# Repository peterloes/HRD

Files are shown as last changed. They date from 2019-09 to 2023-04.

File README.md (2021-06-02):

# A Handheld Readout Device(HRD) for Battery Management Systems
Monitoring Battery Quality and reduce waste.

A standalone HRD to enable long-term diagnostic observations and 
documentation of battery quality.

Supported:

- TEXAS INSTRUMENTS bq40z50
- ATMEL ATmega32HVB

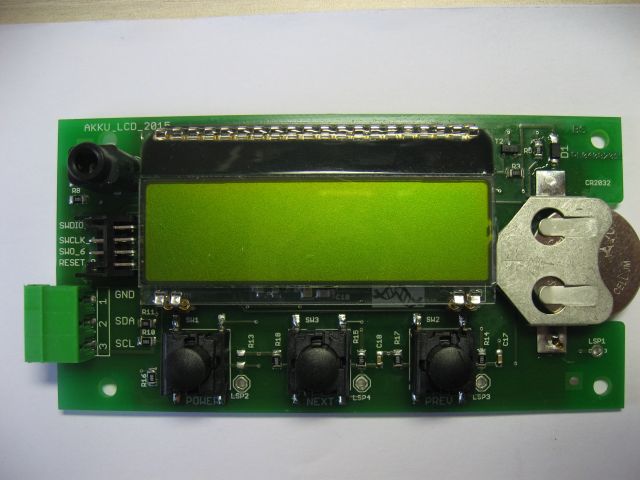
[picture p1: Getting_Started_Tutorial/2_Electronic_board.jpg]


Rechargeable batteries are more and more dominating our modern life.
We find them in our smartphones and notebooks, in e-bikes and e-cars but also in many toys and
basically everywhere where wired power supply is absent.
The charge state of these batteries is usually reported by highlighting a certain portion of a bar, representing full charge.
But is this indication always correct and how can I check whether the full capacity of my battery is still available?

In many rechargeable batteries, technical parameters are controlled by a Battery Management System(BMS).
This device monitors physical parameters like Voltage, Current, Temperature and State of Charge but also
calculates useful values like "Total Number of Charge Cycles", "Total Operation Time since First Use "or"
Energy Delivered since Last Charge".

In product manufacturing, this information is important for checking the battery quality before final assembly
on the product. For battery-driven medical devices, reliable knowledge about the battery status can be crucial.
For the end-user of a battery driven device, access to these data would be beneficial to allow for an informed decision
whether the device could be repaired or needs to be replaced.
 
The efficient use of batteries is especially important, as batteries are difficult to recycle and thus constitute a
burden for the environment. Unfortunately, common BMSs do not display the stored data by default.

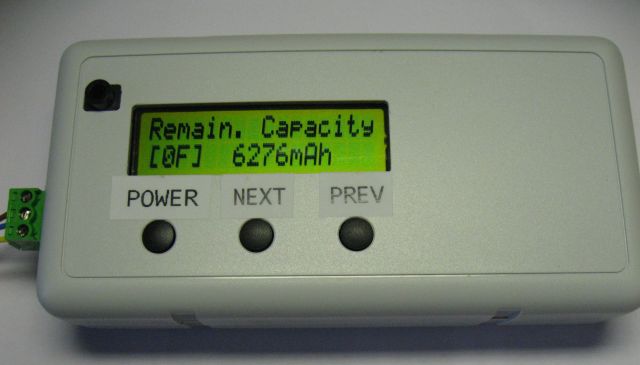
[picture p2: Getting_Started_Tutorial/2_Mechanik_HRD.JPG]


Battery controller probing requests. 0x0A=Atmel, 0x16=TI

Actual Current is signed.

Power management for the LC-Display.

Display will be scrolled (11 digits).

HRD can be connected to external devices like personal computers to transfer and store the extracted technical data.

https://github.com/peterloes/HRD/blob/master/Getting_Started_Tutorial/1_poster_overview.pdf

Manufacture:

https://github.com/peterloes/HRD/blob/master/Getting_Started_Tutorial/3_Supplier.txt

The standalone HRD features EFM32 ...the world´s most energy friendly microcontrollers

ARM Cortex-M3 EFM32G230F128

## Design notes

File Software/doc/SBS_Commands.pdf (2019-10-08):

# Projekt U-BMS2-4

# SBS-

# Commands

# SBS Commands

Device Address | | | | | | 0x0A
ManufacturerAccess | | | | | | 0x00

Read word

RemainingCapacityAlarm | 0x01

Read word
Rückgabe des remainingCapacityAlarm-Wertes in [mAh].

Wenn die Restkapazität(remainingCapacity) kleiner als der Wert vom RemainingCapacityAlarm ist, sendet die Batterie eine Alarmwarnung zum Host. Der RemainingCapacityAlarm-Flag im Battery-Status wird gesetzt.

RemainingTimeAlarm | 0x02

Read word
Rückgabe des remainingTimeAlarm -Wertes in [min].

Wenn die durchschnittliche Entladezeit des Akkus(AverageTimeToEmpty) kleiner als der Wert vom
RemainingTimeAlarm | ist, | sendet | die | Batterie | eine | Alarmwarnung | zum | Host. | Der
RemainingTimeAlarm-Flag im Battery-Status wird gesetzt.
Battery Mode | | | | | | 0x03

Read word

Bit | Beschreibung

### 12 BALANCING CELL3

### 11 BALANCING CELL2

### 10 BALANCING CELL1

### 6 BALANCING CELL4

### 5 Deep Under Voltage recovery(DUVRD) Bit vom FET Control and Status-Register

(FCSR)

### 4 Current Protection Status (CPS) Bit vom FET Control and Status-Register (FCSR)

### 3 Discharge FET (DFE) Bit vom FET Control and Status-Register (FCSR)

### 2 Charge FET (CFE) Bit vom FET Control and Status-Register (FCSR)

CoreTemperature | 0x08

Read word
Die aktuelle Chip-Temperatur in [°K]
Voltage | 0x09

Read word
Die gesamte Akkuspannung in [mV]
BatteryCurrent | 0x0A

Read word
Der aktuelle Strom in [mA], der aus bzw. in den Akkupack durchfließt.
BatteryAverageCurrent | 0x0B

Read word
Der durchschnittliche Strom des Akkupacks in [mA]
RelativeStateOfCharge | 0x0D

Read word
Der relative Ladezustand des Akkupacks in [%]
AbsoluteStateOfCharge | 0x0E

Read word
Der absolute Ladezustand des Akkupacks in [%]
RemainingCapacity | 0x0F

Read word
Die Restkapazität des Akkupacks in [mAh]
FullChargeCapacity | 0x10

Read word
Rückgabe der vollen Ladekapazität in [mAh]
RunTimeToEmpty | 0x11

Read word
Die Ladezeit in [min]
AverageTimeToEmpty | 0x12

Read word
Die durchschnittliche Entladezeit [min]
AverageTimeToFull | 0x13

Read word
Die durchschnittliche Ladezeit in [min]

ChargingCurrent | 0x14

Read word
Der Ladestrom in [mA]
ChargingVoltage | 0x15

Read word
Die maximale Ladespannung in [mV]
Battery Status (flags) | 0x16

Read word

Bit | Beschreibung

### 15 Over Charged Alarm

Überprüfung des chargingProhibited-Flags

### 14 Terminate Charge Alarm

Überprüfung des voltageTooHigh-Flags

### 12 Over Temp Alarm

Überprüfung des cellTemperatureTooHigh -Flags

### 11 Terminante Discharge Alarm

Dieses Bit wird gesetzt, wenn die Restkapazität unter dem definierten Wert von SBS_TERMINATE_DISCHARGE_LIMIT (Standard 5mAh) liegt. Wenn ein Ladegerät erkannt wird, wird dieses Bit gelöscht.

### 10 Battery Protection Triggered

Dieses Bit wird gesetzt, wenn die Batterieschutz-Hardware die FETs ausschaltet.

### 9 Remaining Capacity Alarm

Dieses Bit wird gesetzt, wenn die Restkapazität weniger als der definierte Wert des Restkapazität-Alarms(RemainingCapacityAlarm) ist.

### 8 Remaining Time Alarm :

Wenn die durchschnittlische Entladezeit (AverageTimeToEmpty) kleiner als der definierte Wert des Entladezeit-Alarms (RemainingTimeAlarm) ist, wird dieses Bit gesetzt.

### 7 Initialized

Dieses Bit wird gesetzt, wenn die Initialisierung erfolgreich abgeschlossen ist.

### 6 Discharging

Dieses Bit wird gesetzt, wenn ein Entladestrom fließt.

### 5 Fully Charged

Dieses Bit wird gesetzt, wenn die Batterie vollständig geladen ist. Wenn ein Entladestrom aus der Batterie fließt, der höher als der Standby-Stromwert ist, wird dieses Bit gelöscht.

### 4 Fully Discharged

Dieses Bit wird gesetzt, wenn die Restkapazität der Batterie bzw. die Zellenspannung sehr niedrig ist. Wenn der relative Ladezustand über 20% steigt, wird dieses Bit gelöscht.

ChargerCycleCount | 0x17

Read word
Die Anzahl der Ladezyklen
DesignCapacity | 0x18

Read word
Die Nennkapazität in [mAh]
DesignVoltage | 0x19

Read word
Die Nennspannung in [mV]
SpecificationInfo | 0x1A

Read word
Die Spezifikation-Info (Version und Revision-Nummer)
ManufactureDate | 0x1B

Read word
Das Herstellungsdatum
SerialNumber | 0x1C

Read word
Die Seriennummer
ManufacturerName | 0x20

Read Block
Der Name des Herstellers
DeviceName | 0x21

Read Block
Der Name des Gerätes
DeviceChemistry | 0x22

Read Block
Die chemische Bezeichnung des Gerätes
ManufacturerData | 0x23

Read Block
Die Herstellerdaten
ShuntResistance | 0x2A

Read word
Der Wert des Shunt-Widerstands in [µOhm]

CellsInSeries | 0x3C

Read word
Anzahl der verwendeten Zellen in Serie
OverCurrentReactionTime | 0x3D

Read word
Überstrom Reaktionszeit Stufe 1
OverCurrentCharge | 0x3E

Read word
Überladestrom Stufe 1
OverCurrentDischarge | 0x3F

Read word
Überentladestrom Stufe 1
HighCurrentReactionTime | 0x40

Read word
Überstrom Reaktionszeit Stufe 2
HighCurrentCharge | 0x41

Read word
Überladestrom Reaktionszeit Stufe 2
HighCurrentDischarge | 0x42

Read word
Überentladestrom Stufe 2
VoltageCell4 | 0x44

Read word
Rückgabe der Spannung der Zelle 4 in [mV]
VoltageCell3 | 0x45

Read word
Rückgabe der Spannung der Zelle 3 in [mV]
VoltageCell2 | 0x46

Read word
Rückgabe der Spannung der Zelle 3 in [mV]

VoltageCell1 | 0x47

Read word
Rückgabe der Spannung der Zelle 1 in [mV]
CellMinVoltage | 0x54

Read word
Die minimale Zellenspannung in [mV]
CellMaxVoltage | 0x55

Read word
Der Wert der maximalen Zellenspannung in [mV]
CellPowerOffVoltage | 0x55

Read word
Der Wert der Zellenspannung in [mV], bei der das BMS in den PowerOffModus geht

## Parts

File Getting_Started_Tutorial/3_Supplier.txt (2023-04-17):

Supplier of all Electronic Boards

Top-Print Electronic GmbH
Oskar Schmid

Rosenheimer Landstr. 129a
85521 Ottobrunn
Germany
Tel.: +49-89-60668047
Fax: +49-89-60668049
mailto: info@top-print.eu
https://www.leiterplatten-muenchen.de/

https://www.reichelt.com

1 	× 	Housing TEKO Mod.10008
3 	× 	5GSH935+1SS09-12.0 (Button)
24 	× 	Pin Header, vertical to increase display height. manufacturer number: MK01/50 Z.
1 	× 	Phoenix Contact MC 1.5/ 3-G-3.81 manufacturer number: 1803280
1 	× 	PTR Socket housing-cable AK(Z)1550 manufacturer number: 51550030025F
1 	× 	FTDI Chip cable (3.5mm Audio Jack to USB) TTL-232R-3V3-AJ 

Docklight RS232 Terminal / RS232 Monitor
https://docklight.de/information/

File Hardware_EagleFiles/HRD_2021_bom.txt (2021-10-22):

Part  Value                         Device           Package          Description                                                    MF MPN OC_FARNELL OC_NEWARK
BH1   KEYSTONE_CELL_CLIP 3082 3082             3082                                                                                                       
C1    100n                          C-EUC0805K       C0805K           CAPACITOR, European symbol                                                                
C2    1u                            C-EUC0805K       C0805K           CAPACITOR, European symbol                                                                
C3    12p                           C-EUC0805K       C0805K           CAPACITOR, European symbol                                                                
C4    18p                           C-EUC0805K       C0805K           CAPACITOR, European symbol                                                                
C5    100n                          C-EUC0805K       C0805K           CAPACITOR, European symbol                                                                
C6    100n                          C-EUC0805K       C0805K           CAPACITOR, European symbol                                                                
C7    100n                          C-EUC0805K       C0805K           CAPACITOR, European symbol                                                                
C8    100n                          C-EUC0805K       C0805K           CAPACITOR, European symbol                                                                
C9    12p                           C-EUC0805K       C0805K           CAPACITOR, European symbol                                                                
C10   18p                           C-EUC0805K       C0805K           CAPACITOR, European symbol                                                                
C11   100n                          C-EUC0805K       C0805K           CAPACITOR, European symbol                                                                
C12   100n                          C-EUC0805K       C0805K           CAPACITOR, European symbol                                                                
C13   100n                          C-EUC0805K       C0805K           CAPACITOR, European symbol                                                                
C14   100n                          C-EUC0805K       C0805K           CAPACITOR, European symbol                                                                
C15   100n                          C-EUC0805K       C0805K           CAPACITOR, European symbol                                                                
C16   100n                          C-EUC0805K       C0805K           CAPACITOR, European symbol                                                                
C17   10n                           C-EUC0603K       C0603K           CAPACITOR, European symbol                                                                
C18   10n                           C-EUC0603K       C0603K           CAPACITOR, European symbol                                                                
C19   470n                          C-EUC0603K       C0603K           CAPACITOR, European symbol                                                                
C20   100n                          C-EUC0603K       C0603K           CAPACITOR, European symbol                                                                
C21   100nF                         C-EUC0603K       C0603K           CAPACITOR, European symbol                                                                
D1    RSX101M-30              DIODE-SOD123     SOD123           DIODE                                                                                     
IC1   EFM32G230F128                 EFM32G230F128    QFN64            EFM32G230F128 Gecko Microcontroller in 9mm x 9mm QFN64 package                            
J1    LUMBERG1502_01                LUMBERG1502_01   LUMBERG1502_01                                                                                             
LCD1  EA_DOGM162L-A           EA_DOGM162       EA_DOGM          ELECTRONIC ASSEMBYL GmbH                                                                  
LSP1  (n.b.)LSP13                   LSP13            LSP13            SOLDER PAD drill 1.3 mm, distributor Buerklin, 12H562                                     
LSP2  (n.b.)SE13                    SE13             SE13             SOLDER PAD E1542,  drill 1,3mm, distributor Buerklin, 07F815                              
LSP3  (n.b.)SE13                    SE13             SE13             SOLDER PAD E1542,  drill 1,3mm, distributor Buerklin, 07F815                              
LSP4  (n.b.)SE13                    SE13             SE13             SOLDER PAD E1542,  drill 1,3mm, distributor Buerklin, 07F815                              
PASS1 ROUND_1MM1.5                  ROUND_1MM1.5     ROUND2_1.5MM                                                                                               
PASS2 ROUND_1MM1.5                  ROUND_1MM1.5     ROUND2_1.5MM                                                                                               
Q1    NX5032GA/32MHz/8pF            CRYSTAL2P5.0X3.2 CRYSTAL2P5.0X3.2 Quarz Crystal                                                                             
Q2    CM7V, 32768Hz/12.5pF          CRYSTAL2P        CRYSTAL2P3.2X1.5 Quarz Crystal                                                                             
R1    100                           R-EU_R0805       R0805            RESISTOR, European symbol                                                                 
R2    100K                          R-EU_R0805       R0805            RESISTOR, European symbol                                                                 
R3    100K                          R-EU_R0805       R0805            RESISTOR, European symbol                                                                 
R4    100                           R-EU_R0805       R0805            RESISTOR, European symbol                                                                 
R5    100K                          R-EU_R0805       R0805            RESISTOR, European symbol                                                                 
R6    100                           R-EU_R0805       R0805            RESISTOR, European symbol                                                                 
R7    100K                          R-EU_R0805       R0805            RESISTOR, European symbol                                                                 
R8    10K                           R-EU_R0805       R0805            RESISTOR, European symbol                                                                 
R9    10K                           R-EU_R0805       R0805            RESISTOR, European symbol                                                                 
R10   1K                            R-EU_R0805       R0805            RESISTOR, European symbol                                                                 
R11   1K                            R-EU_R0805       R0805            RESISTOR, European symbol                                                                 
R12   1                             R-EU_R0805       R0805            RESISTOR, European symbol                                                                 
R13   (n.b.)100K                    R-EU_R0805       R0805            RESISTOR, European symbol                                                                 
R14   100K                          R-EU_R0805       R0805            RESISTOR, European symbol                                                                 
R15   100K                          R-EU_R0805       R0805            RESISTOR, European symbol                                                                 
R16   100                           R-EU_R0805       R0805            RESISTOR, European symbol                                                                 
R17   100                           R-EU_R0805       R0805            RESISTOR, European symbol                                                                 
R18   100                           R-EU_R0805       R0805            RESISTOR, European symbol                                                                 
R19   100                           R-EU_R0805       R0805            RESISTOR, European symbol                                                                 
R20   100K                          R-EU_R0805       R0805            RESISTOR, European symbol                                                                 
R21   100K                          R-EU_R0805       R0805            RESISTOR, European symbol                                                                 
R22   100                           R-EU_R0805       R0805            RESISTOR, European symbol                                                                 
R23   100K                          R-EU_R0805       R0805            RESISTOR, European symbol                                                                 
SW1   5GSH935                 5GSH935          MULTIMEC_5GSH935                                                                                           
SW2   5GSH935                 5GSH935          MULTIMEC_5GSH935                                                                                           
SW3   5GSH935                 5GSH935          MULTIMEC_5GSH935                                                                                           
T1    2N7002                        NMOSSOT23        SOT-23           MOS FET                                                               unknown    unknown  
T2    FDN358P                       ZETEX_PMOSSOT23  ZETEX_SOT-23     MOS FET                                                                                   
T3    2N7002                        NMOSSOT23        SOT-23           MOS FET                                                               unknown    unknown  
T4    2N7002                        ZETEX_NMOSSOT23  ZETEX_SOT-23     MOS FET                                                                                   
T5    FDN358P                       ZETEX_PMOSSOT23  ZETEX_SOT-23     MOS FET                                                                                   
X1    DF11_8DP_2DS            DP11_8DP_2DS     DP11_8DP-2DS                                                                                               
X2    MKDS1/3-3,81            MKDS1/3-3,81     3POL381          MKDS 1/3-3,81 - manufacturer number: Order No. 1803280                          
   
LCD1 under  24 × Pin Header, vertical to increase display height. manufacturer number: MK01/50 Z
X2 Phoenix Contact MC 1.5/ 3-G-3.81 manufacturer number: 1803280 

Housing TEKO Mod.10008 
5GSH935+1SS09-12.0 (Buttons)
PTR Socket housing-cable AK(Z)1550 manufacturer number: 51550030025F
FTDI Chip cable (3.5mm Audio Jack to USB) TTL-232R-3V3-AJ

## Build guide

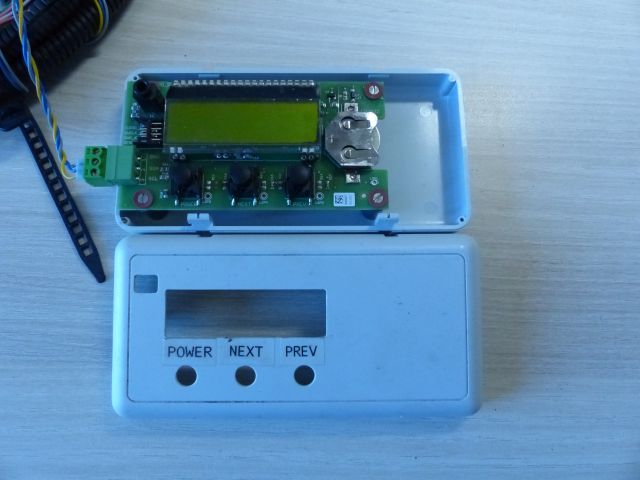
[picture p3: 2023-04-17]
Getting_Started_Tutorial/4_housing.jpg

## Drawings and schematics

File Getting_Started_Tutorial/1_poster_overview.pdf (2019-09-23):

## Handheld Readout Device (HRD)

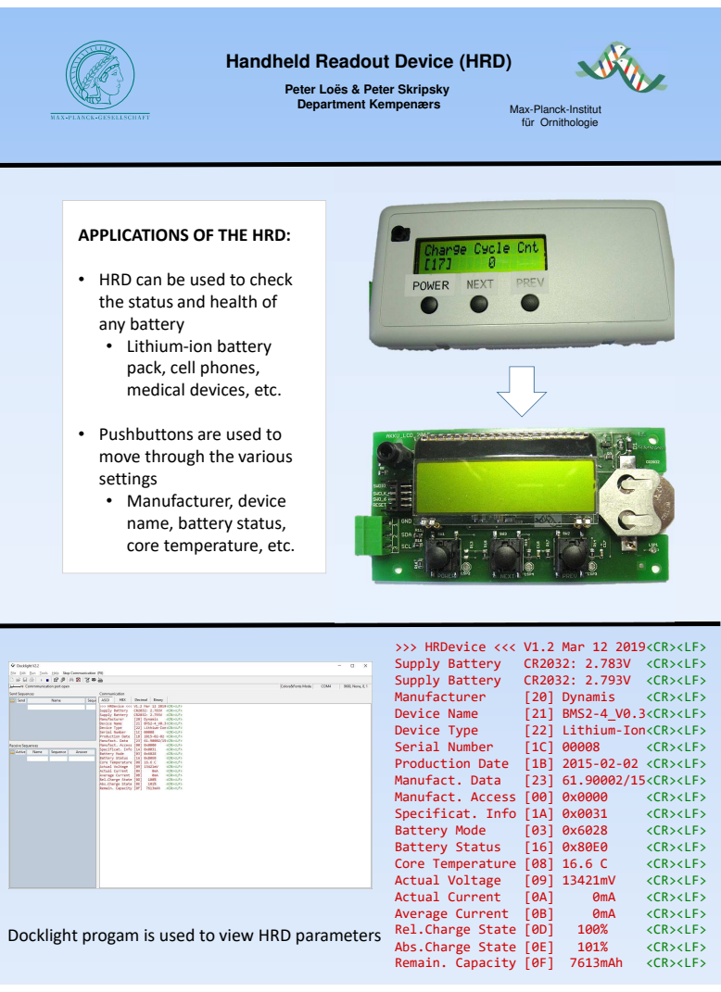
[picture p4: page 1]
Supply Battery; Manufacturer; [20] Dynamis; Device Name; [21] BMS2-4_V0.3<CR><LF>; Device Type; [22] Lithium-Ion<CR><LF>; Serial Number; Production Date; Manufact. Data; Manufact. Access [00] 0x0000; Specificat. Info [1A] 0x0031; Battery Mode; Battery Status; Core Temperature [08] 16.6 C; Actual Voltage; Actual Current; Average Current; Rel.Charge State [0D]; Abs.Charge State [0E]; Remain. Capacity [0F]; 7613mAh

Peter Loës & Peter Skripsky
Department Kempenærs

Max-Planck-Institut
für Ornithologie

APPLICATIONS OF THE HRD:

• HRD can be used to check
the status and health of
any battery
• Lithium-ion battery
pack, cell phones,
medical devices, etc.

• Pushbuttons are used to
move through the various
settings
• Manufacturer, device
name, battery status,
core temperature, etc.

>>> HRDevice <<< V1.2 Mar 12 2019<CR><LF>

Docklight progam is used to view HRD parameters

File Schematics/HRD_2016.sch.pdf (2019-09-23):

# EFM32 Power SMBUS / ATmega 32 HVB

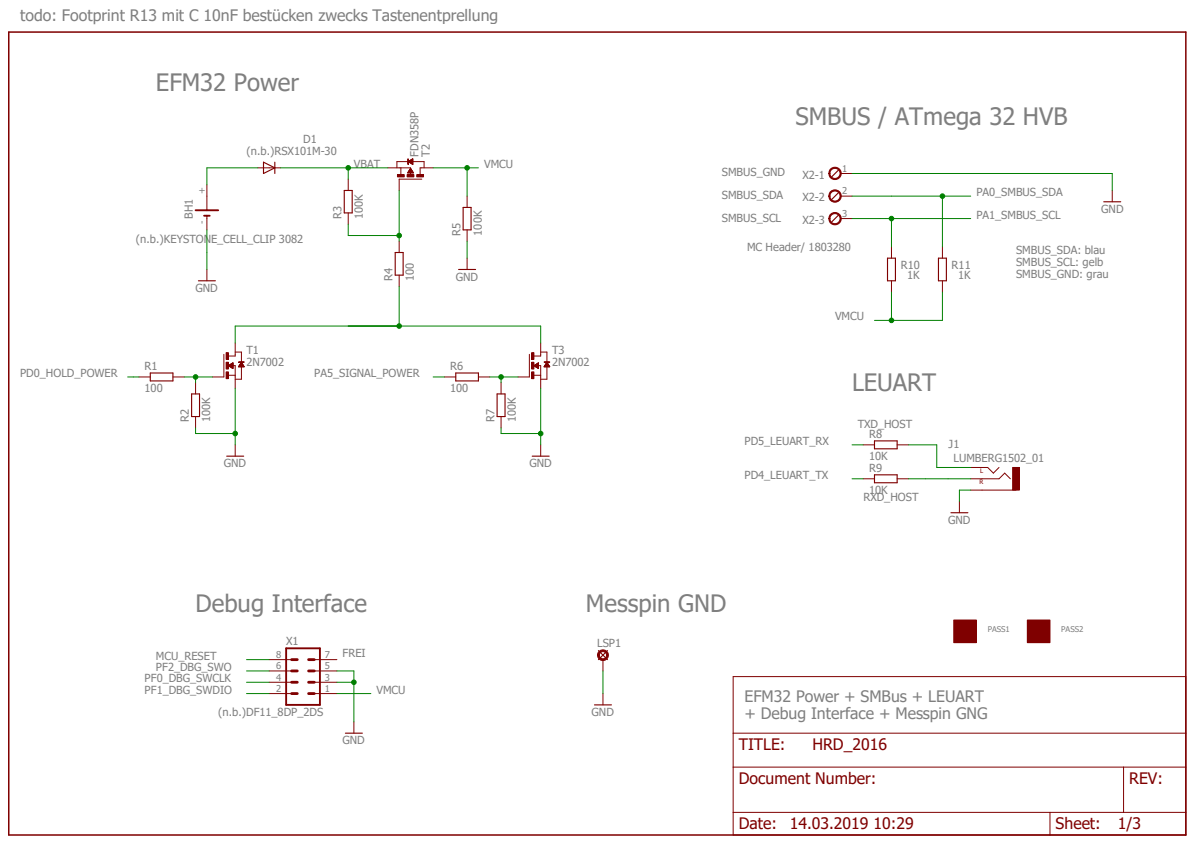
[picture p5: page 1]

todo: Footprint R13 mit C 10nF bestücken zwecks Tastenentprellung

EFM32 Power + SMBus + LEUART
+ Debug Interface + Messpin GNG

Document Number: | REV:

Date: 14.03.2019 10:29 | Sheet: 1/3

# EFM32 I/O + POWER

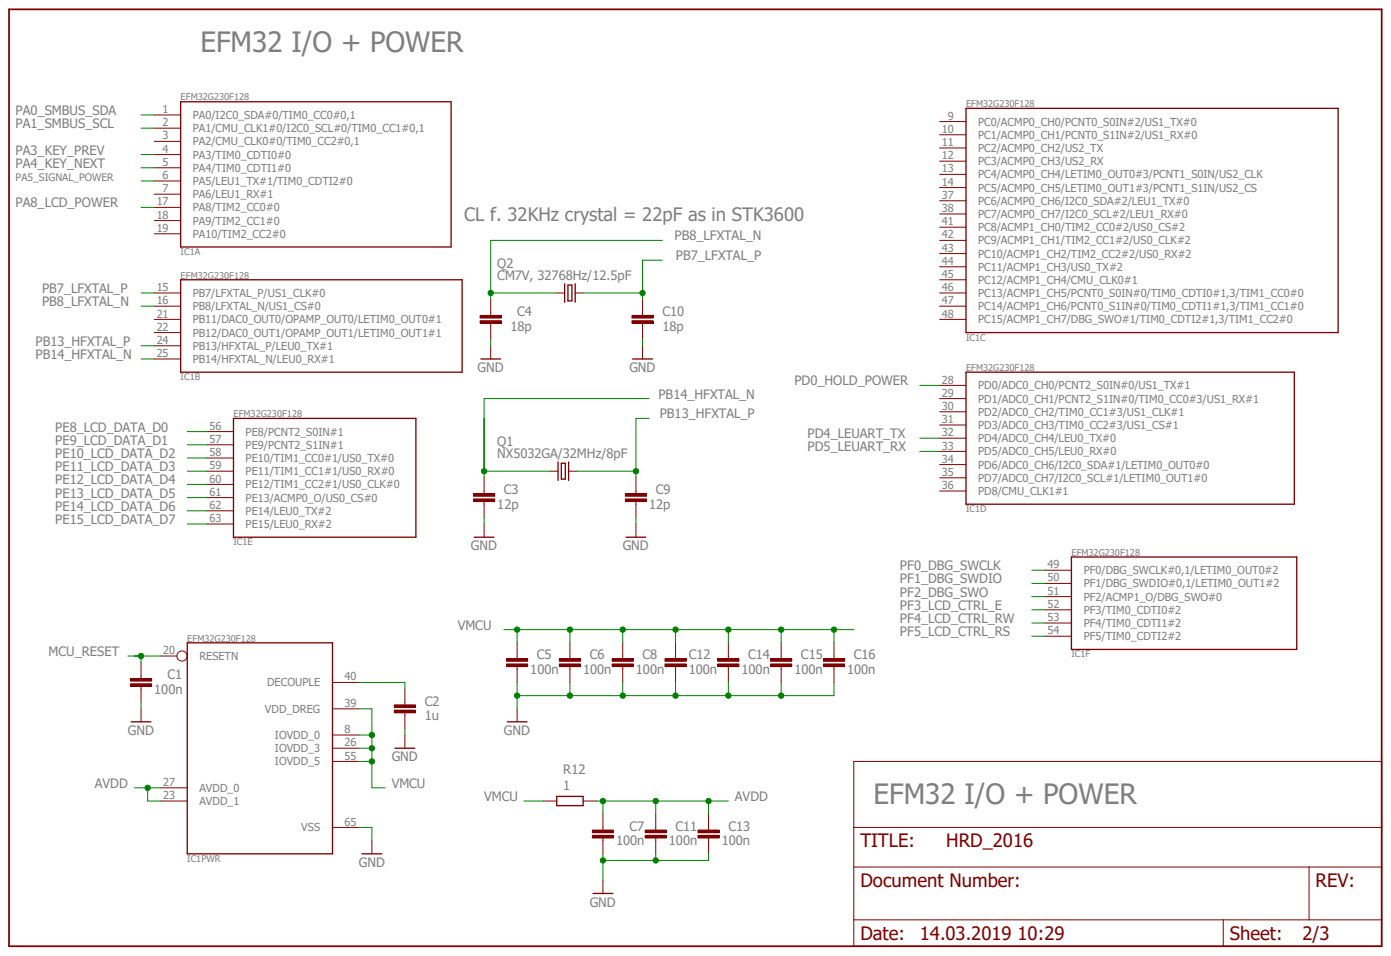
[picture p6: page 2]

CL f. 32KHz crystal = 22pF as in STK3600

Document Number: | REV:

Date: 14.03.2019 10:29 | Sheet: 2/3

# Display

Pushbutton | gemessen: AN 342uA

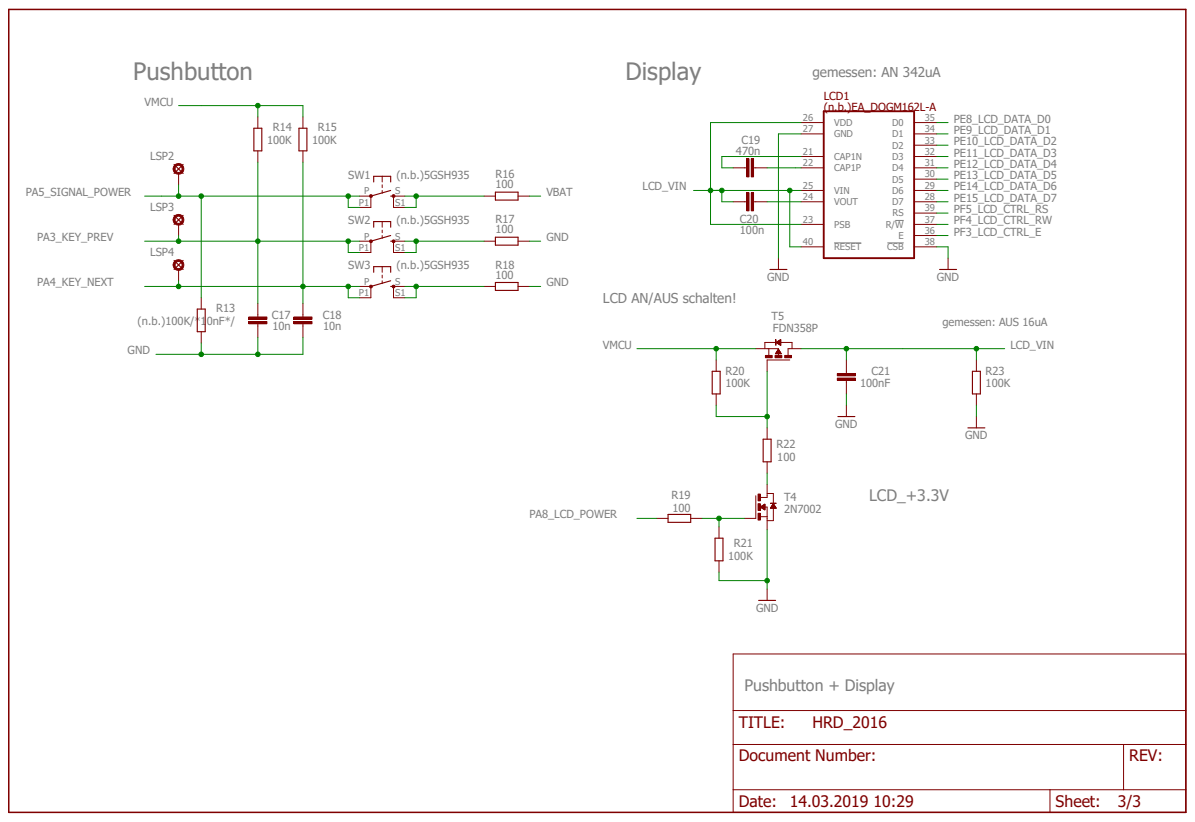
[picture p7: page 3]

LCD AN/AUS schalten!

Document Number: | REV:

Date: 14.03.2019 10:29 | Sheet: 3/3

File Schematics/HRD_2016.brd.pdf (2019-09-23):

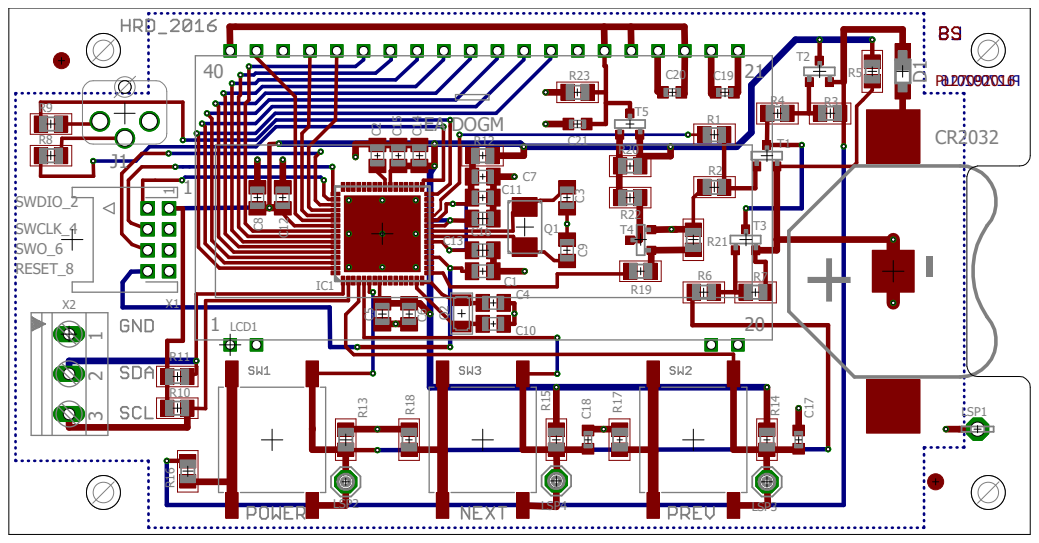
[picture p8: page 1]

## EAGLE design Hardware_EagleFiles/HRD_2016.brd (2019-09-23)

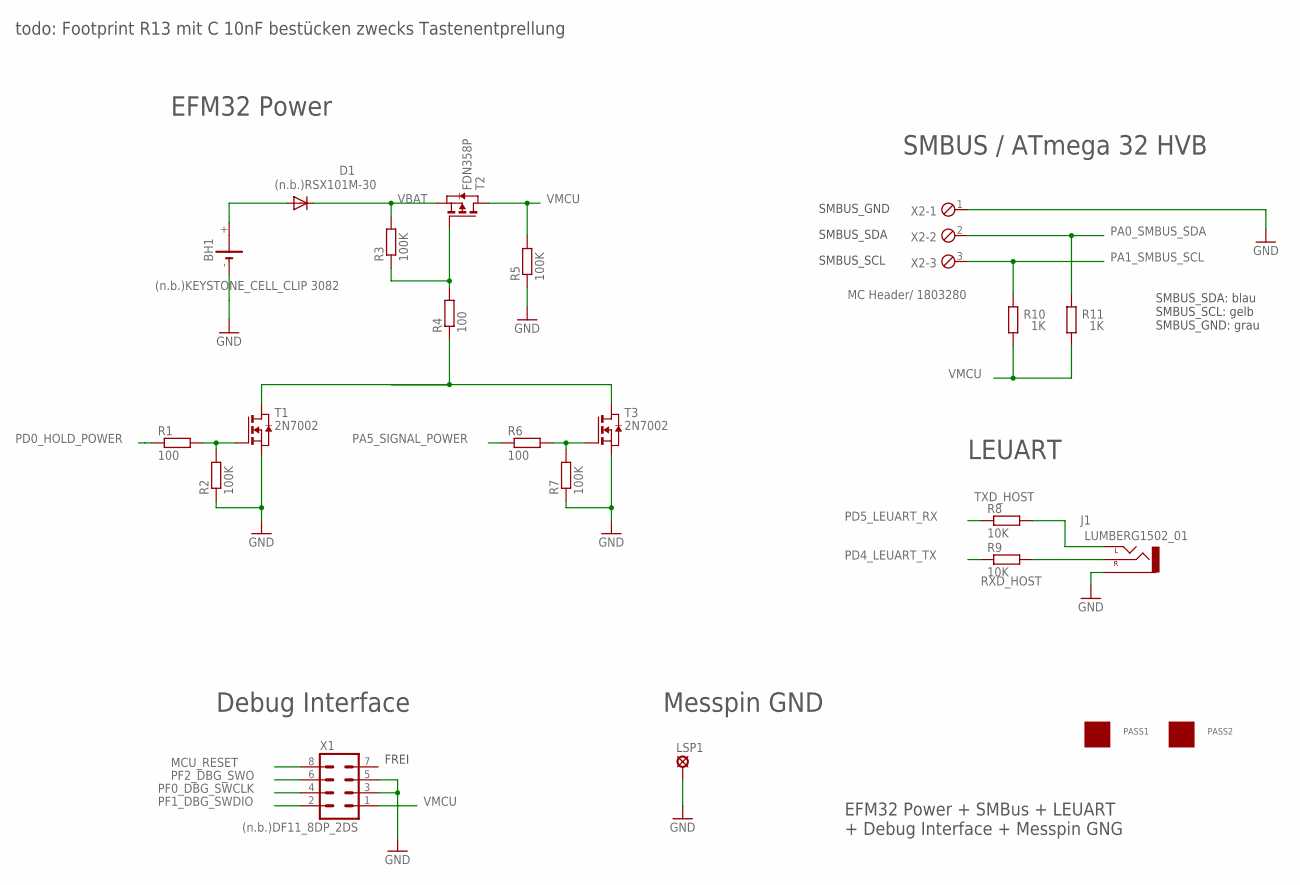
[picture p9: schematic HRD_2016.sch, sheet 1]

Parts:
BH1: (n.b.)KEYSTONE_CELL_CLIP 3082; 3082
D1: (n.b.)RSX101M-30; SOD123
J1: LUMBERG1502_01
LSP1: (n.b.)LSP13; LSP13
PASS1, PASS2: ROUND_1MM1.5; ROUND2_1.5MM
R1, R4, R6: 100; R0805
R2, R3, R5, R7: 100K; R0805
R8, R9: 10K; R0805
R10, R11: 1K; R0805
T1, T3: 2N7002; SOT-23
T2: FDN358P; ZETEX_SOT-23
X1: (n.b.)DF11_8DP_2DS; DP11_8DP-2DS
X2: MC Header/ 1803280; 3POL381

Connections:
GND: BH1.-, J1.P$1 (1-SLEEVE), LSP1.MP, R2.1, R5.1, R7.1, T1.2 (S), T3.2 (S), X1.3, X1.5, X2.1; also elsewhere on the board
MCU_RESET: X1.8; also elsewhere on the board
unnamed: BH1.+, D1.A
unnamed: R1.2, R2.2, T1.3 (G)
unnamed: R4.1, T1.1 (D), T3.1 (D)
unnamed: R6.2, R7.2, T3.3 (G)
unnamed: R3.1, R4.2, T2.3 (G)
PA0_SMBUS_SDA: R11.2, X2.2; also elsewhere on the board
PA1_SMBUS_SCL: R10.2, X2.3; also elsewhere on the board
PA5_SIGNAL_POWER: R6.1; also elsewhere on the board
PD0_HOLD_POWER: R1.1; also elsewhere on the board
PD4_LEUART_TX: R9.1; also elsewhere on the board
PD5_LEUART_RX: R8.1; also elsewhere on the board
PF0_DBG_SWCLK: X1.4; also elsewhere on the board
PF1_DBG_SWDIO: X1.2; also elsewhere on the board
PF2_DBG_SWO: X1.6; also elsewhere on the board
RXD_HOST: J1.P$3 (3-RIGHT), R9.2
TXD_HOST: J1.P$2 (2-LEFT), R8.2
VBAT: D1.C, R3.2, T2.2 (S); also elsewhere on the board
VMCU: R5.2, R10.1, R11.1, T2.1 (D), X1.1; also elsewhere on the board

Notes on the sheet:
EFM32 Power + SMBus + LEUART + Debug Interface + Messpin GNG
SMBUS_SCL
SMBUS_SDA
SMBUS_GND
EFM32 Power
Debug Interface
SMBUS / ATmega 32 HVB
FREI
SMBUS_SDA: blau SMBUS_SCL: gelb SMBUS_GND: grau
Messpin GND
LEUART
todo: Footprint R13 mit C 10nF bestücken zwecks Tastenentprellung

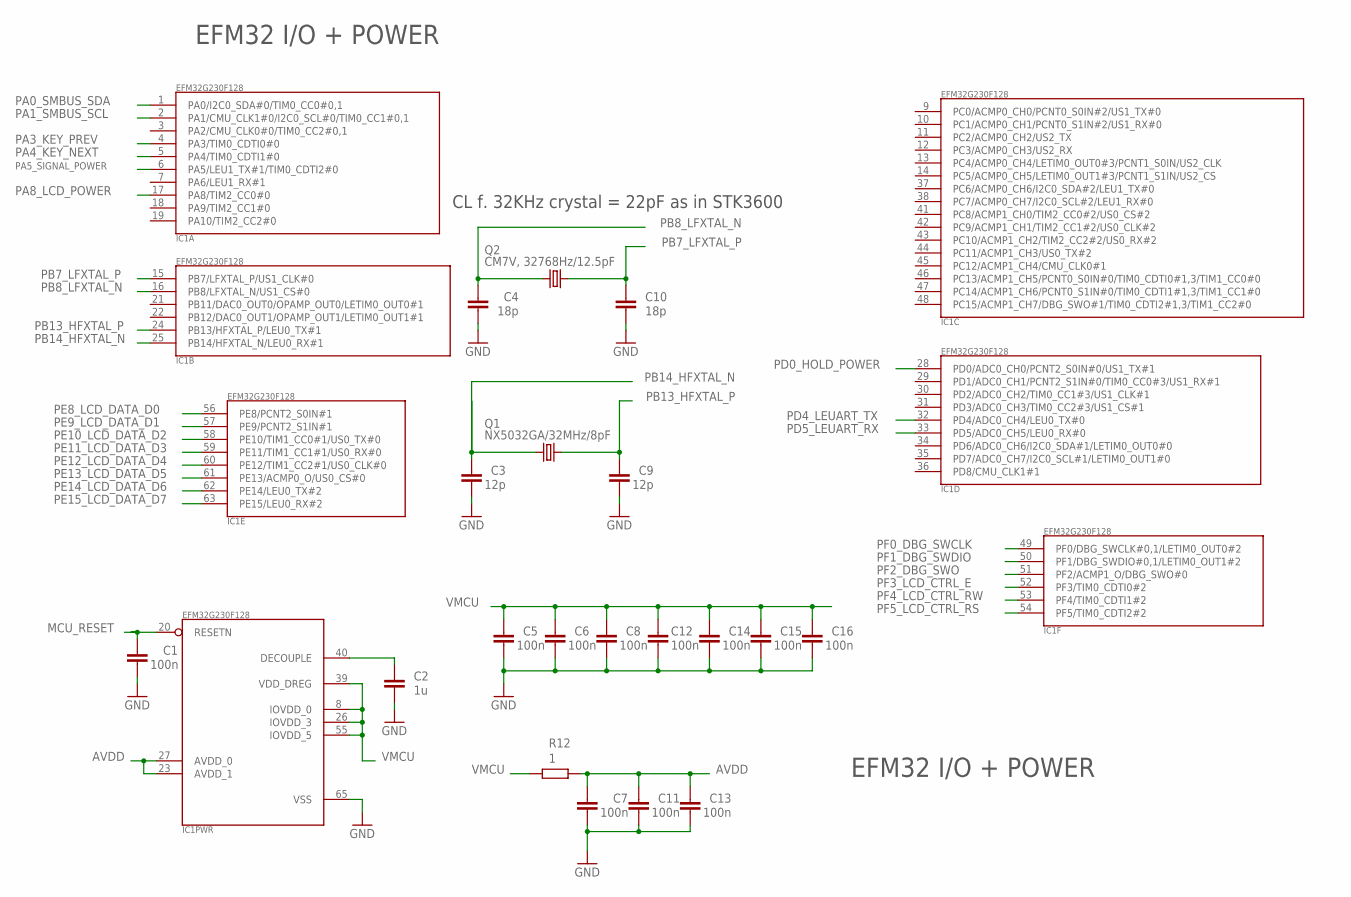
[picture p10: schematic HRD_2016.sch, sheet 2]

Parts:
C1, C5, C6, C7, C8, C11, C12, C13, C14, C15, C16: 100n; C0805K
C2: 1u; C0805K
C3, C9: 12p; C0805K
C4, C10: 18p; C0805K
IC1: EFM32G230F128; QFN64
Q1: NX5032GA/32MHz/8pF; CRYSTAL2P5.0X3.2
Q2: CM7V, 32768Hz/12.5pF; CRYSTAL2P3.2X1.5
R12: 1; R0805

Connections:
AVDD: C7.2, C11.2, C13.2, IC1.23 (AVDD_1), IC1.27 (AVDD_0), R12.2
GND: C1.1, C2.1, C3.1, C4.1, C5.1, C6.1, C7.1, C8.1, C9.1, C10.1, C11.1, C12.1, C13.1, C14.1, C15.1, C16.1, IC1.65 (VSS); also elsewhere on the board
MCU_RESET: C1.2, IC1.20 (RESETN); also elsewhere on the board
unnamed: C2.2, IC1.40 (DECOUPLE)
PA0_SMBUS_SDA: IC1.1 (PA0/I2C0_SDA#0/TIM0_CC0#0,1); also elsewhere on the board
PA1_SMBUS_SCL: IC1.2 (PA1/CMU_CLK1#0/I2C0_SCL#0/TIM0_CC1#0,1); also elsewhere on the board
PA3_KEY_PREV: IC1.4 (PA3/TIM0_CDTI0#0); also elsewhere on the board
PA4_KEY_NEXT: IC1.5 (PA4/TIM0_CDTI1#0); also elsewhere on the board
PA5_SIGNAL_POWER: IC1.6 (PA5/LEU1_TX#1/TIM0_CDTI2#0); also elsewhere on the board
PA8_LCD_POWER: IC1.17 (PA8/TIM2_CC0#0); also elsewhere on the board
PB7_LFXTAL_P: C10.2, IC1.15 (PB7/LFXTAL_P/US1_CLK#0), Q2.2
PB8_LFXTAL_N: C4.2, IC1.16 (PB8/LFXTAL_N/US1_CS#0), Q2.1
PB13_HFXTAL_P: C9.2, IC1.24 (PB13/HFXTAL_P/LEU0_TX#1), Q1.2
PB14_HFXTAL_N: C3.2, IC1.25 (PB14/HFXTAL_N/LEU0_RX#1), Q1.1
PD0_HOLD_POWER: IC1.28 (PD0/ADC0_CH0/PCNT2_S0IN#0/US1_TX#1); also elsewhere on the board
PD4_LEUART_TX: IC1.32 (PD4/ADC0_CH4/LEU0_TX#0); also elsewhere on the board
PD5_LEUART_RX: IC1.33 (PD5/ADC0_CH5/LEU0_RX#0); also elsewhere on the board
PE8_LCD_DATA_D0: IC1.56 (PE8/PCNT2_S0IN#1); also elsewhere on the board
PE9_LCD_DATA_D1: IC1.57 (PE9/PCNT2_S1IN#1); also elsewhere on the board
PE10_LCD_DATA_D2: IC1.58 (PE10/TIM1_CC0#1/US0_TX#0); also elsewhere on the board
PE11_LCD_DATA_D3: IC1.59 (PE11/TIM1_CC1#1/US0_RX#0); also elsewhere on the board
PE12_LCD_DATA_D4: IC1.60 (PE12/TIM1_CC2#1/US0_CLK#0); also elsewhere on the board
PE13_LCD_DATA_D5: IC1.61 (PE13/ACMP0_O/US0_CS#0); also elsewhere on the board
PE14_LCD_DATA_D6: IC1.62 (PE14/LEU0_TX#2); also elsewhere on the board
PE15_LCD_DATA_D7: IC1.63 (PE15/LEU0_RX#2); also elsewhere on the board
PF0_DBG_SWCLK: IC1.49 (PF0/DBG_SWCLK#0,1/LETIM0_OUT0#2); also elsewhere on the board
PF1_DBG_SWDIO: IC1.50 (PF1/DBG_SWDIO#0,1/LETIM0_OUT1#2); also elsewhere on the board
PF2_DBG_SWO: IC1.51 (PF2/ACMP1_O/DBG_SWO#0); also elsewhere on the board
PF3_LCD_CTRL_E: IC1.52 (PF3/TIM0_CDTI0#2); also elsewhere on the board
PF4_LCD_CTRL_RW: IC1.53 (PF4/TIM0_CDTI1#2); also elsewhere on the board
PF5_LCD_CTRL_RS: IC1.54 (PF5/TIM0_CDTI2#2); also elsewhere on the board
VMCU: C5.2, C6.2, C8.2, C12.2, C14.2, C15.2, C16.2, IC1.8 (IOVDD_0), IC1.26 (IOVDD_3), IC1.39 (VDD_DREG), IC1.55 (IOVDD_5), R12.1; also elsewhere on the board

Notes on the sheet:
EFM32 I/O + POWER
CL f. 32KHz crystal = 22pF as in STK3600

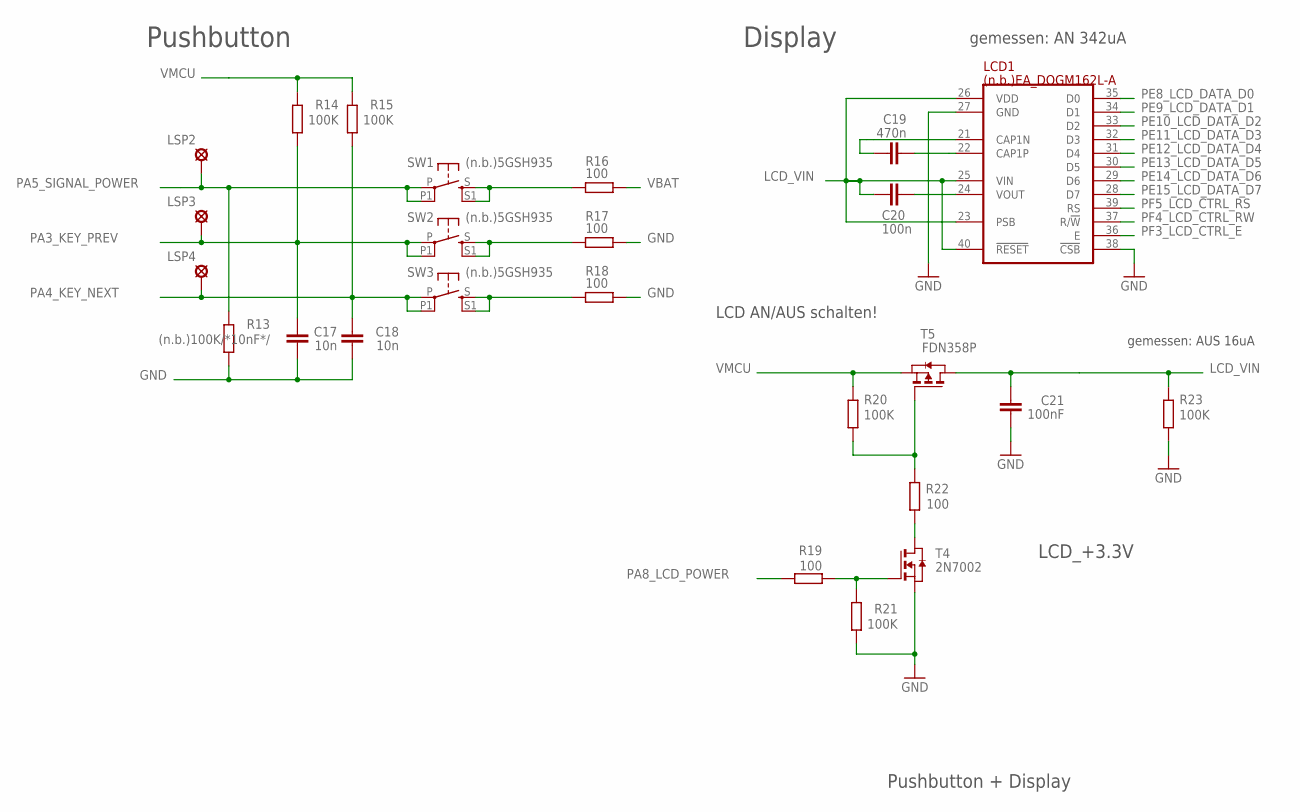
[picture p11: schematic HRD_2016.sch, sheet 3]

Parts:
C17, C18: 10n; C0603K
C19: 470n; C0603K
C20: 100n; C0603K
C21: 100nF; C0603K
LCD1: (n.b.)EA_DOGM162L-A; EA_DOGM
LSP2, LSP3, LSP4: (n.b.)SE13; SE13
R13: (n.b.)100K/*10nF*/; R0805
R14, R15, R20, R21, R23: 100K; R0805
R16, R17, R18, R19, R22: 100; R0805
SW1, SW2, SW3: (n.b.)5GSH935; MULTIMEC_5GSH935
T4: 2N7002; ZETEX_SOT-23
T5: FDN358P; ZETEX_SOT-23

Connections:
GND: C17.1, C18.1, C21.2, LCD1.27 (GND), LCD1.38 (!CSB!), R13.1, R17.2, R18.2, R21.1, R23.1, T4.2 (S); also elsewhere on the board
LCD_VIN: C20.2, C21.1, LCD1.23 (PSB), LCD1.25 (VIN), LCD1.26 (VDD), LCD1.40 (!RESET!), R23.2, T5.1 (D)
unnamed: R17.1, SW2.S, SW2.S1
unnamed: R16.1, SW1.S, SW1.S1
unnamed: R18.1, SW3.S, SW3.S1
unnamed: R20.1, R22.2, T5.3 (G)
unnamed: R22.1, T4.1 (D)
unnamed: R19.1, R21.2, T4.3 (G)
unnamed: C19.2, LCD1.22 (CAP1P)
unnamed: C19.1, LCD1.21 (CAP1N)
unnamed: C20.1, LCD1.24 (VOUT)
PA3_KEY_PREV: C17.2, LSP3.MP, R14.1, SW2.P, SW2.P1; also elsewhere on the board
PA4_KEY_NEXT: C18.2, LSP4.MP, R15.1, SW3.P, SW3.P1; also elsewhere on the board
PA5_SIGNAL_POWER: LSP2.MP, R13.2, SW1.P, SW1.P1; also elsewhere on the board
PA8_LCD_POWER: R19.2; also elsewhere on the board
PE8_LCD_DATA_D0: LCD1.35 (D0); also elsewhere on the board
PE9_LCD_DATA_D1: LCD1.34 (D1); also elsewhere on the board
PE10_LCD_DATA_D2: LCD1.33 (D2); also elsewhere on the board
PE11_LCD_DATA_D3: LCD1.32 (D3); also elsewhere on the board
PE12_LCD_DATA_D4: LCD1.31 (D4); also elsewhere on the board
PE13_LCD_DATA_D5: LCD1.30 (D5); also elsewhere on the board
PE14_LCD_DATA_D6: LCD1.29 (D6); also elsewhere on the board
PE15_LCD_DATA_D7: LCD1.28 (D7); also elsewhere on the board
PF3_LCD_CTRL_E: LCD1.36 (E); also elsewhere on the board
PF4_LCD_CTRL_RW: LCD1.37 (R/!W!); also elsewhere on the board
PF5_LCD_CTRL_RS: LCD1.39 (RS); also elsewhere on the board
VBAT: R16.2; also elsewhere on the board
VMCU: R14.2, R15.2, R20.2, T5.2 (S); also elsewhere on the board

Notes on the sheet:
Pushbutton + Display
Display
gemessen: AUS 16uA
LCD_+3.3V
LCD AN/AUS schalten!
gemessen: AN 342uA
Pushbutton

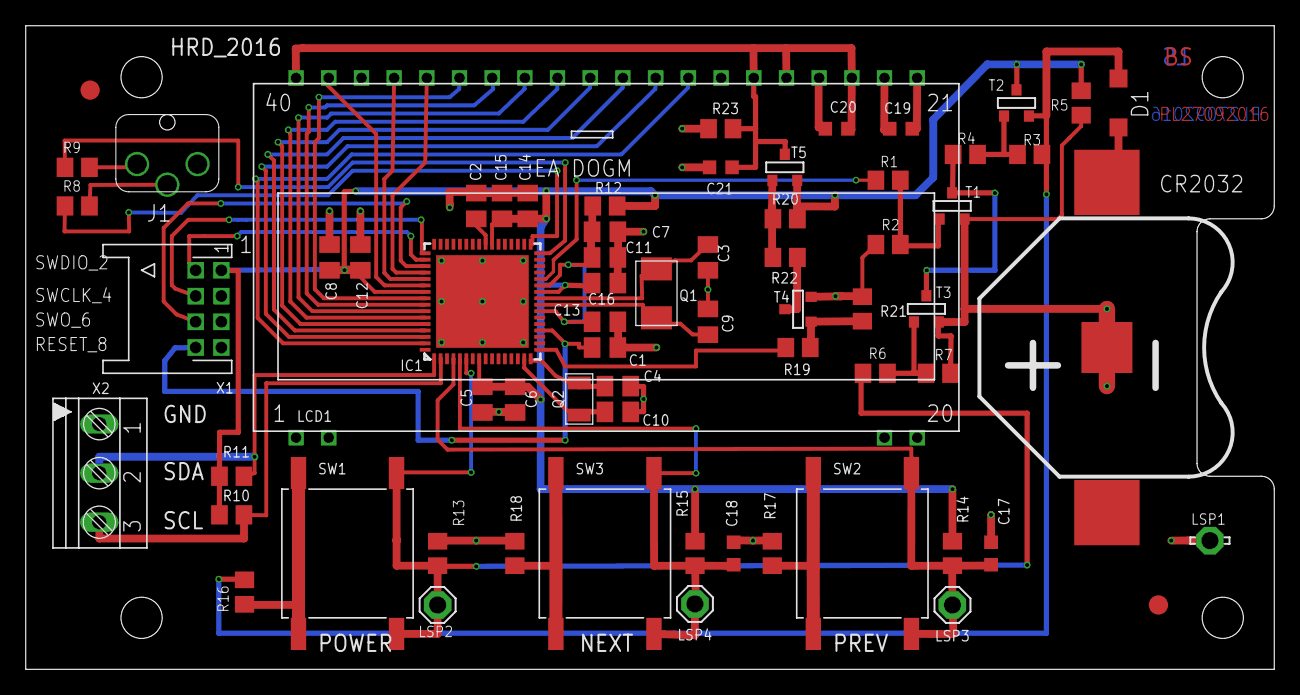
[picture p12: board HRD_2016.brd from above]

Board: 2 copper layers, 97.0 x 50.0 mm, 67 parts (0 on the bottom side), 50 nets.

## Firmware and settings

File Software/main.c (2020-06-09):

/***************************************************************************//**
 * @file
 * @brief	HRD
 * @author	Peter Loes
 * @version	2020-01-13
 *
 * This application consists of the following modules:
 * - ExtInt.c - External interrupt handler.
 * - Keys.c - Key interrupt handling and translation.
 * - AlarmClock.c - Alarm clock and timers facility.
 * - clock.c - An implementation of the POSIX time() function.
 * - LCD_DOGM162.c - Driver for the DOGM162 LC-Display.
 * - LEUART.c - Driver for the Low-Energy UART.
 * - Display.c - Display manager for LCD.
 * - BatteryMon.c - Battery monitor, allows to read the state of the
 *   battery via the SMBus.
 *
 * Parts of the code are based on the example code of AN0006 "tickless calender"
 * from Energy Micro AS.
 *
 ***************************************************************************//**
 *
 * Parts are Copyright 2013 Energy Micro AS, http://www.energymicro.com
 *
 *******************************************************************************
 *
 * Permission is granted to anyone to use this software for any purpose,
 * including commercial applications, and to alter it and redistribute it
 * freely, subject to the following restrictions:
 *
 * 1. The origin of this software must not be misrepresented; you must not
 *    claim that you wrote the original software.
 * 2. Altered source versions must be plainly marked as such, and must not be
 *    misrepresented as being the original software.
 * 3. This notice may not be removed or altered from any source distribution.
 * 4. The source and compiled code may only be used on Energy Micro "EFM32"
 *    microcontrollers and "EFR4" radios.
 *
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
 * Energy Micro AS will not be liable for any consequential, incidental, or
 * special damages, or any other relief, or for any claim by any third party,
 * arising from your use of this Software.
 *
 ****************************************************************************//*
Revision History:
2020-01-13,rage	Merged with version from Peter Loes, updated documentation.
		Calculate the LCD contrast depending on the CR2032 voltage.
		ConsolePrintf() allows formated output to the serial console.
2016-11-22,rage	Added DMA Channel Assignment for LEUART support.
		Changed l_ExtIntCfg for new version of ExtInt module.
		Initialize LEUART.
		Use separate format types for Overcurrent and Highcurrent
		Reaction Times.
2015-10-12,rage	Removed LED initialization, updated documentation.
2015-06-22,rage	Initial version.
*/

/*!
 * @mainpage
 * <b>Description</b><br>
 * HRD (Handheld Readout Device) is an application to display actual values of a
 * battery pack. For that purpose the HRD board must be connected to the battery
 * controller via its SMBus.
 *
 * The system consists of the following components:
 *
 * <b>Microcontroller</b><br>
 * The heart of the board is an EFM32G230 microcontroller.  It provides two
 * different clock domains: All low-energy peripheral is clocked via a
 * 32.768kHz external XTAL.  The MCU and other high performance peripheral
 * uses a high-frequency clock.  The board can be configured to use the
 * internal RC-oscillator, or an external 32MHz XTAL for that purpose,
 * see define @ref USE_EXT_32MHZ_CLOCK.
 *
 * <b>Keys (Push Buttons)</b><br>
 * There exist 3 push buttons on the board (description of the keys is left to
 * right).  When asserted, the following action will be taken:
 * - <b>POWER</b> button.  It is used to switch the device on or off (for
 *   switching it off keep the button asserted until the text message
 *   <b>POWER OFF</b> is displayed).
 *   When pressed for a short time, it shows the firmware version and date, and
 *   probes for the battery controller again.  This is useful after a different
 *   battery pack has been connected to the HRD.
 * - <b>NEXT</b> key.  It leads to the next menu item that is applicable for
 *   the connected battery controller.
 *   This key has a auto-repeat functionality when kept asserted.
 * - <b>PREV</b> key.  It returns to the previous menu item.
 *   This key has a auto-repeat functionality when kept asserted.
 *
 * The duration how long the respective information is displayed before
 * switching the LCD off again, can be adjusted by the define @ref
 * LCD_POWER_OFF_TIMEOUT.
 *
 * Another timeout define is the @ref POWER_OFF_TIMEOUT.  It specifies the
 * number of seconds after which the whole device is powered off if no
 * key assertion is detected.  @ref POWER_OFF_TIMEOUT should be greater
 * or equal @ref LCD_POWER_OFF_TIMEOUT.
 *
 * <b>LC-Display</b><br>
 * The display provides 2 lines á 16 characters.  It is connected to the
 * EFM32 microcontroller via a parallel bus interface.  To save power, the
 * whole display usually is switched off and only activated by asserting a
 * push button.  After a power-up or reset, the LCD displays the firmware
 * version until a push button is asserted.
 *
 * The visual contrast of the LCD can be adjusted via @ref l_Contrast.
 *
 * <b>Battery Monitor</b><br>
 * The battery pack has its own controller.  It is connected to the EFM32
 * microcontroller via I²C-bus (SMBus).  The battery monitor routines  allow to
 * request status information from the battery pack.  This module additionally
 * provides function ReadVdd() to read the voltage of the local supply battery.
 *
 * <b>Firmware</b><br>
 * The firmware consists of an initialization part and a main loop, also called
 * service execution loop.  The initialization part sets up all modules, enables
 * devices and interrupts.  The service execution loop handles all tasks that
 * must not be executed in interrupt context.
 *
 * After power-up or reset the following actions are performed:
 * -# Basic initialization of MCU and clocks
 * -# The Hold-Power pin is activated
 * -# Further hardware initialization (Keys, Interrupts, Alarm Clock)
 * -# The LC-Display is activated and the firmware version is shown
 * -# The Battery Monitor is initialized
 * -# If a Battery Pack is connected via SMBus, the controller type is probed
 *    and displayed
 *
 * The program then enters the Service Execution Loop which takes care of:
 * - Power management for the LC-Display
 * - Manual or timed Power-Off
 * - Battery controller probing requests via POWER button
 * - Battery monitoring
 * - Entering the right energy mode
 */
/*=============================== Header Files ===============================*/

#include <stdio.h>
#include "em_device.h"
#include "em_chip.h"
#include "em_cmu.h"
#include "em_emu.h"
#include "em_dma.h"
#include "config.h"		// include project configuration parameters
#include "ExtInt.h"
#include "Keys.h"
#include "AlarmClock.h"
#include "Display.h"
#include "LCD_DOGM162.h"
#include "LEUART.h"

/*================================ Global Data ===============================*/

extern char const prjVersion[];
extern char const prjDate[];


/*! @brief Global DMA Control Block.
 *
 * It contains the configuration for all 8 DMA channels which may be used by
 * various peripheral devices, e.g. ADC, DAC, USART, LEUART, I2C, and others.
 * The entries of this array will be set by the initialization routines of the
 * driver, which was assigned to the respective channel.  Unused entries remain
 * zero.  There is a total of 16 entries in the array.  The first 8 are used
 * for the primary DMA structures, the second 8 for alternate DMA structures
 * as used for DMA scatter-gather mode, where one buffer is still available,
 * while the other can be re-configured.  This application uses only the first
 * 8 entries.
 *
 * @see  DMA Channel Assignment
 *
 * @note This array must be aligned to 256!
 */
#if defined (__ICCARM__)
    #pragma data_alignment=256
    DMA_DESCRIPTOR_TypeDef g_DMA_ControlBlock[DMA_CHAN_COUNT * 2];
#elif defined (__CC_ARM)
    DMA_DESCRIPTOR_TypeDef g_DMA_ControlBlock[DMA_CHAN_COUNT * 2] __attribute__ ((aligned(256)));
#elif defined (__GNUC__)
    DMA_DESCRIPTOR_TypeDef g_DMA_ControlBlock[DMA_CHAN_COUNT * 2] __attribute__ ((aligned(256)));
#else
    #error Undefined toolkit, need to define alignment
#endif


/*! @brief Global DMA Callback Structure.
 *
 * This array contains the addresses of the DMA callback functions, which are
 * executed for a dedicated DMA channel at the end of a DMA transfer.
 * The entries of this array will be set by the initialization routines of the
 * driver, which was assigned to the respective channel.  Unused entries remain
 * zero.
 */
DMA_CB_TypeDef g_DMA_Callback[DMA_CHAN_COUNT];

/*! @brief Flag to indicate that an Interrupt occurred in the meantime.
 *
 * This flag must be set <b>true</b> by any interrupt service routine that
 * requires actions in the service execution loop of main().  This prevents
 * the system from entering sleep mode, so the action can be taken before.
 */
volatile bool		g_flgIRQ;

/*! @brief Modules that require EM1.
 *
 * This global variable is a bit mask for all modules that require EM1.
 * Standard peripherals would stop working in EM2 because clocks, etc. are
 * disabled.  Therefore it is required for software modules that make use
 * of such devices, to set the appropriate bit in this mask, as long as they
 * need EM1.  This prevents the power management of this application to enter
 * EM2.  The enumeration @ref EM1_MODULES lists those modules.
 * Low-Power peripherals, e.g. the LEUART still work in EM1.
 *
 * Examples:
 *
   @code
   // Module RFID requires EM1, set bit in bit mask
   Bit(g_EM1_ModuleMask, EM1_MOD_RFID) = 1;
   ...
   // Module RFID is no longer active, clear bit in bit mask
   Bit(g_EM1_ModuleMask, EM1_MOD_RFID) = 0;
   @endcode
 */
volatile uint16_t	g_EM1_ModuleMask;

/*================================ Local Data ================================*/

    /*! EXTI initialization structure
     *
     * Connect the external interrupts of the push buttons to the key handler.
     */
static const EXTI_INIT  l_ExtIntCfg[] =
{   //	IntBitMask,	IntFct
    {	KEY_EXTI_MASK,	KeyHandler	},	// Keys
    {	0,		NULL		}
};

    /*!
     * Initialization structure to define the timings for the autorepeat (AR)
     * threshold and rate (in milliseconds), and a function to be called for
     * each translated key.
     */
static const KEY_INIT  l_KeyInit =
{
    .AR_Threshold = AUTOREPEAT_THRESHOLD,
    .AR_Rate	= AUTOREPEAT_RATE,
    .KeyFct	= DisplayKeyHandler
};

    /*! LCD field definitions
     *
     * This array specifies the location and size of fields on the LC-Display.
     *
     * @warning	Enum @ref LCD_FIELD_ID is used as index within this array,
     * 		therefore care has to be taken to keep it "in sync"!
     */
static const LCD_FIELD l_LCD_Field[LCD_FIELD_ID_CNT] =
{
    /* X,  Y,	Width	*/
    {  0,  0,	16	},	//!< 0: LCD_LINE1_BLANK
    {  0,  1,	16	},	//!< 1: LCD_LINE2_BLANK
    {  0,  0,	16	},	//!< 2: LCD_LINE1_TEXT
    {  0,  1,	16	},	//!< 3: LCD_LINE2_TEXT
    {  0,  0,	16	},	//!< 4: LCD_ITEM_DESC
    {  0,  1,	16	},	//!< 5: LCD_ITEM_ADDR
    {  5,  1,	11	},	//!< 6: LCD_ITEM_DATA
    {  0,  0,	16	},	//!< 7: LCD_CLOCK (no RTC, just display the uptime)
};

    /*! List of items which can be displayed
     *
     * This array contains a list of items that can be displayed on the LCD.
     * Element 0 is a special case, it shows the name, version, and date of
     * the firmware image.  Usually up/down push buttons are used to select
     * the item to be displayed.
     *
     * The order of these items may be rearranged by the user.  Single or
     * groups of entries can be de-activated by commenting them out.
     */
static const ITEM l_Item[] =
{  // [1234567890123456]    Cmd				Frmt
    { ">>> HRDevice <<<",   SBS_NONE,			FRMT_FW_VERSION	},
    { "Battery at SMBus",   SBS_NONE,			FRMT_BAT_CTRL	},
    { "Supply Battery",     SBS_NONE,			FRMT_CR2032_BAT	},
    { "Manufacturer",       SBS_ManufacturerName,	FRMT_STRING	},
    { "Device Name",        SBS_DeviceName,		FRMT_STRING	},
    { "Device Type",        SBS_DeviceChemistry,	FRMT_STRING	},
    { "Serial Number",      SBS_SerialNumber,		FRMT_HEX	},
    { "Production Date",    SBS_ManufactureDate,	FRMT_DATE	},
    { "Manufact. Data",	    SBS_ManufacturerData,	FRMT_STRING	},
    { "Manufact. Data",	    SBS_ManufacturerDataTI,	FRMT_STRING	},
    { "Specificat. Info",   SBS_SpecificationInfo,	FRMT_HEX	},
    { "Design Capacity",    SBS_DesignCapacity,		FRMT_MILLIAMPH	},
    { "Design Voltage",     SBS_DesignVoltage,		FRMT_MILLIVOLT	},
    { "Battery Mode",       SBS_BatteryMode,		FRMT_HEX	},
    { "Battery Status",     SBS_BatteryStatus,		FRMT_HEX	},
    { "Core Temperature",   SBS_Temperature,		FRMT_TEMP	},
    { "Actual Voltage",     SBS_Voltage,		FRMT_MILLIVOLT	},
    { "Actual Current",     SBS_Current,		FRMT_MILLIAMP	},
    { "Average Current",    SBS_AverageCurrent, 	FRMT_MILLIAMP	},
    { "Rel.Charge State",   SBS_RelativeStateOfCharge,	FRMT_PERCENT	},
    { "Abs.Charge State",   SBS_AbsoluteStateOfCharge,	FRMT_PERCENT	},
    { "Remain. Capacity",   SBS_RemainingCapacity,	FRMT_MILLIAMPH	},
    { "Remain.Cap.Alarm",   SBS_RemainingCapacityAlarm,	FRMT_MILLIAMPH	},
    { "Remain.TimeAlarm",   SBS_RemainingTimeAlarm,	FRMT_DURATION	},
    { "Full Charge Cap.",   SBS_FullChargeCapacity,	FRMT_MILLIAMPH	},
    { "Runtime to Empty",   SBS_RunTimeToEmpty,		FRMT_DURATION	},
    { "Av.Time to Empty",   SBS_AverageTimeToEmpty,	FRMT_DURATION	},
    { "Avr.Time to Full",   SBS_AverageTimeToFull,	FRMT_DURATION	},
    { "Charging Current",   SBS_ChargingCurrent,	FRMT_MILLIAMP	},
    { "Charging Voltage",   SBS_ChargingVoltage,	FRMT_MILLIVOLT	},
    { "Charge Cycle Cnt",   SBS_CycleCount,		FRMT_INTEGER	},
	/* ATMEL Controller */
    { "Shunt Resistance",   SBS_ShuntResistance,	FRMT_MICROOHM	},
    { "Overcurr. React.",   SBS_OverCurrentReactionTime,FRMT_OC_REATIME },
    { "Overcurr. Charge",   SBS_OverCurrentCharge,	FRMT_MILLIAMP	},
    { "Overcurr.Dischar",   SBS_OverCurrentDischarge,	FRMT_MILLIAMP	},
    { "Highcurr. React.",   SBS_HighCurrentReactionTime,FRMT_HC_REATIME },
    { "Highcurr. Charge",   SBS_HighCurrentCharge,	FRMT_MILLIAMP	},
    { "Highcurr.Dischar",   SBS_HighCurrentDischarge,	FRMT_MILLIAMP	},
    { "Cells in series",    SBS_CellsInSeries,		FRMT_INTEGER	},
    { "Cell #1 Voltage",    SBS_VoltageCell1,		FRMT_MILLIVOLT	},
    { "Cell #2 Voltage",    SBS_VoltageCell2,		FRMT_MILLIVOLT	},
    { "Cell #3 Voltage",    SBS_VoltageCell3,		FRMT_MILLIVOLT	},
    { "Cell #4 Voltage",    SBS_VoltageCell4,		FRMT_MILLIVOLT	},
    { "Cell Min Voltage",   SBS_CellMinVoltage,		FRMT_MILLIVOLT	},
    { "Cell Max Voltage",   SBS_CellMaxVoltage,		FRMT_MILLIVOLT	},
    { "Cell PwrOff Volt",   SBS_CellPowerOffVoltage,	FRMT_MILLIVOLT	},
	/* TI Controller */
    { "Cell #1 Voltage",    SBS_CellVoltage1,		FRMT_MILLIVOLT	},
    { "Cell #2 Voltage",    SBS_CellVoltage2,		FRMT_MILLIVOLT	},
    { "Cell #3 Voltage",    SBS_CellVoltage3,		FRMT_MILLIVOLT	},
    { "Cell #4 Voltage",    SBS_CellVoltage4,		FRMT_MILLIVOLT	},
    { "State-of-Health",    SBS_StateOfHealth,		FRMT_PERCENT	},
};
#define ITEM_CNT	ELEM_CNT(l_Item)

/*=========================== Forward Declarations ===========================*/

static void cmuSetup(void);


/******************************************************************************
 * @brief  Main function
 *****************************************************************************/
int main( void )
{
    /* Initialize chip - handle erratas */
    CHIP_Init();

    /* Set up clocks */
    cmuSetup();

    /* Enable FET to power the device independent from the Power Button */
    PowerUp();

    /* Init Low Energy UART with 9600bd (this is the maximum) */
    drvLEUART_Init (9600);

#ifdef DEBUG
    dbgInit();

    /* Output version string to SWO or LEUART */
    DBG_PUTS("\n***** HRDevice V");
    DBG_PUTS(prjVersion);
    DBG_PUTS(" ");
    DBG_PUTS(prjDate);
    DBG_PUTS(" *****\n\n");
#endif

    /*
     * All modules that make use of external interrupts (EXTI) should be
     * initialized before calling ExtIntInit() because this enables the
     * interrupts, so IRQ handler may be executed immediately!
     */

    /* Initialize key hardware */
    KeyInit (&l_KeyInit);

    /*
     * Initialize (and enable) External Interrupts
     */
    ExtIntInit (l_ExtIntCfg);

    /* Initialize the Alarm Clock module */
    AlarmClockInit();

    /* Verify element count */
    EFM_ASSERT(ELEM_CNT(l_LCD_Field) == LCD_FIELD_ID_CNT);

    /*
     * Set Contrast of LC-Display.  This depends on the CR2032 Battery Voltage:
     * 2.9V -> 30, 2.6V -> 45, i.e. 5 digits per 100mV, 1 digit per 20mV
     * Contrast calculation must be done before initializing the LCD!
     */
    LCD_SetContrast((3500 - ReadVdd()) / 20);

    /* Initialize display - show firmware version */
    DisplayInit (l_LCD_Field, l_Item, ITEM_CNT);
    LCD_Printf (LCD_LINE1_TEXT, ">>> HRDevice <<<");
    LCD_Printf (LCD_LINE2_TEXT, "V%s %s", prjVersion, prjDate);

    /* Initialize Battery Monitor */
    BatteryMonInit();

    /* Enable all other External Interrupts */
    ExtIntEnableAll();


    /* ============================================ *
     * ========== Service Execution Loop ========== *
     * ============================================ */
    while (1)
    {
	/* Update or power-off the LC-Display, update measurements */
	DisplayUpdateCheck();

	/*
	 * Check for current power mode:  If a minimum of one active module
	 * requires EM1, i.e. <g_EM1_ModuleMask> is not 0, this will be
	 * entered.  If no one requires EM1 activity, EM2 is entered.
	 */
	if (! g_flgIRQ)		// enter EM only if no IRQ occured
	{
	    if (g_EM1_ModuleMask)
		EMU_EnterEM1();		// EM1 - Sleep Mode
	    else
		EMU_EnterEM2(true);	// EM2 - Deep Sleep Mode
	}
	else
	{
	    g_flgIRQ = false;	// clear flag to enter EM the next time
	}
    }
}


/******************************************************************************
 * @brief   Configure Clocks
 *
 * This local routine is called once from main() to configure all required
 * clocks of the EFM32 device.
 *
 *****************************************************************************/
static void cmuSetup(void)
{
    /* Start LFXO and wait until it is stable */
    CMU_OscillatorEnable(cmuOsc_LFXO, true, true);

#if USE_EXT_32MHZ_CLOCK
    /* Start HFXO and wait until it is stable */
    CMU_OscillatorEnable(cmuOsc_HFXO, true, true);

    /* Select HFXO as clock source for HFCLK */
    CMU_ClockSelectSet(cmuClock_HF, cmuSelect_HFXO);

    /* Disable HFRCO */
    CMU_OscillatorEnable(cmuOsc_HFRCO, false, false);
#endif

    /* Route the LFXO clock to the RTC and set the prescaler */
    CMU_ClockSelectSet(cmuClock_LFA, cmuSelect_LFXO);	// RTC
    CMU_ClockSelectSet(cmuClock_LFB, cmuSelect_LFXO);	// LEUART0/1
    CMU_ClockEnable(cmuClock_RTC, true);

    /* Prescaler of 1 = 30 us of resolution and overflow each 8 min */
    CMU_ClockDivSet(cmuClock_RTC, cmuClkDiv_1);

    /* Enable clock to low energy modules */
    CMU_ClockEnable(cmuClock_CORELE, true);

    /* Enable clock for HF peripherals (ADC, DAC, I2C, TIMER, and USART) */
    CMU_ClockEnable(cmuClock_HFPER, true);

    /* Enable clock to GPIO */
    CMU_ClockEnable(cmuClock_GPIO, true);
}


/***************************************************************************//**
 *
 * @brief	Print string to serial console
 *
 * This routine is used to print text to the serial console, i.e. LEUART.
 *
 * @param[in] frmt
 *	Format string of the text to print - same as for printf().
 *
 * @see		drvLEUART_puts()
 *
 ******************************************************************************/
void ConsolePrintf (const char *frmt, ...)
{
char	 buffer[120];
va_list	 args;


    va_start (args, frmt);
    vsprintf (buffer, frmt, args);
    drvLEUART_puts (buffer);
    va_end (args);
}

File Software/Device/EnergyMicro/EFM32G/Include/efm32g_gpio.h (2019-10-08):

/**************************************************************************//**
 * @file
 * @brief efm32g_gpio Register and Bit Field definitions
 * @author Energy Micro AS
 * @version 3.20.2
 ******************************************************************************
 * @section License
 * <b>(C) Copyright 2012 Energy Micro AS, http://www.energymicro.com</b>
 ******************************************************************************
 *
 * Permission is granted to anyone to use this software for any purpose,
 * including commercial applications, and to alter it and redistribute it
 * freely, subject to the following restrictions:
 *
 * 1. The origin of this software must not be misrepresented; you must not
 *    claim that you wrote the original software.
 * 2. Altered source versions must be plainly marked as such, and must not be
 *    misrepresented as being the original software.
 * 3. This notice may not be removed or altered from any source distribution.
 *
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
 * Energy Micro AS will not be liable for any consequential, incidental, or
 * special damages, or any other relief, or for any claim by any third party,
 * arising from your use of this Software.
 *
 *****************************************************************************/
/**************************************************************************//**
 * @defgroup EFM32G_GPIO
 * @{
 * @brief EFM32G_GPIO Register Declaration
 *****************************************************************************/
typedef struct
{
  GPIO_P_TypeDef P[6];          /**< Port configuration bits */

  uint32_t       RESERVED0[10]; /**< Reserved for future use **/
  __IO uint32_t  EXTIPSELL;     /**< External Interrupt Port Select Low Register  */
  __IO uint32_t  EXTIPSELH;     /**< External Interrupt Port Select High Register  */
  __IO uint32_t  EXTIRISE;      /**< External Interrupt Rising Edge Trigger Register  */
  __IO uint32_t  EXTIFALL;      /**< External Interrupt Falling Edge Trigger Register  */
  __IO uint32_t  IEN;           /**< Interrupt Enable Register  */
  __I uint32_t   IF;            /**< Interrupt Flag Register  */
  __IO uint32_t  IFS;           /**< Interrupt Flag Set Register  */
  __IO uint32_t  IFC;           /**< Interrupt Flag Clear Register  */

  __IO uint32_t  ROUTE;         /**< I/O Routing Register  */
  __IO uint32_t  INSENSE;       /**< Input Sense Register  */
  __IO uint32_t  LOCK;          /**< Configuration Lock Register  */
} GPIO_TypeDef;                 /** @} */

/**************************************************************************//**
 * @defgroup EFM32G_GPIO_BitFields
 * @{
 *****************************************************************************/

/* Bit fields for GPIO P_CTRL */
#define _GPIO_P_CTRL_RESETVALUE                           0x00000000UL                           /**< Default value for GPIO_P_CTRL */
#define _GPIO_P_CTRL_MASK                                 0x00000003UL                           /**< Mask for GPIO_P_CTRL */
#define _GPIO_P_CTRL_DRIVEMODE_SHIFT                      0                                      /**< Shift value for GPIO_DRIVEMODE */
#define _GPIO_P_CTRL_DRIVEMODE_MASK                       0x3UL                                  /**< Bit mask for GPIO_DRIVEMODE */
#define _GPIO_P_CTRL_DRIVEMODE_DEFAULT                    0x00000000UL                           /**< Mode DEFAULT for GPIO_P_CTRL */
#define _GPIO_P_CTRL_DRIVEMODE_STANDARD                   0x00000000UL                           /**< Mode STANDARD for GPIO_P_CTRL */
#define _GPIO_P_CTRL_DRIVEMODE_LOWEST                     0x00000001UL                           /**< Mode LOWEST for GPIO_P_CTRL */
#define _GPIO_P_CTRL_DRIVEMODE_HIGH                       0x00000002UL                           /**< Mode HIGH for GPIO_P_CTRL */
#define _GPIO_P_CTRL_DRIVEMODE_LOW                        0x00000003UL                           /**< Mode LOW for GPIO_P_CTRL */
#define GPIO_P_CTRL_DRIVEMODE_DEFAULT                     (_GPIO_P_CTRL_DRIVEMODE_DEFAULT << 0)  /**< Shifted mode DEFAULT for GPIO_P_CTRL */
#define GPIO_P_CTRL_DRIVEMODE_STANDARD                    (_GPIO_P_CTRL_DRIVEMODE_STANDARD << 0) /**< Shifted mode STANDARD for GPIO_P_CTRL */
#define GPIO_P_CTRL_DRIVEMODE_LOWEST                      (_GPIO_P_CTRL_DRIVEMODE_LOWEST << 0)   /**< Shifted mode LOWEST for GPIO_P_CTRL */
#define GPIO_P_CTRL_DRIVEMODE_HIGH                        (_GPIO_P_CTRL_DRIVEMODE_HIGH << 0)     /**< Shifted mode HIGH for GPIO_P_CTRL */
#define GPIO_P_CTRL_DRIVEMODE_LOW                         (_GPIO_P_CTRL_DRIVEMODE_LOW << 0)      /**< Shifted mode LOW for GPIO_P_CTRL */
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

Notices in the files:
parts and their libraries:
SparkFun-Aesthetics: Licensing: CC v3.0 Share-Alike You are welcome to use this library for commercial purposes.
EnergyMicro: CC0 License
